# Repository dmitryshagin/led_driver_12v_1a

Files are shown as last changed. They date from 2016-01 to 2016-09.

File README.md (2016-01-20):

***WARNING! IT'S UNTESTED - I'VE NEVER BUILT THIS BOARD. But I will :)***

LED driver for powering Cree XHP35 LED at 1.05A from 3S LiPoly battery to use in underwater flashlight.

It's currently tuned up to work with 9-12.6V input.

Input can be easily changed to 4-25V with slight adjustment of R2 and R3. Increasing voltage over 25V is limited by used capacitors and FETs. You can change it upto ~60V with selecting new Q1-Q5, but PCB rework is also required.

Current is roughly set to 2A with R11, and is fine-tuned to 1.048A with R14&R15. Tuning R14 and R15 values makes it possible to set any current between 0-2A.

This driver is build around [LT3791](http://www.linear.com/product/LT3791)

I've also added Attiny24 to control PWM input and monitor input voltage. It can be ignored and never placed. Firmware will be added later, but the idea is to detect power loss with Q6, go to deep sleep and change working mode on power recovery. C16 gives uC ~4 seconds of life in power down mode, so we can switch power modes with one romote switch. Simulation gave me 10us for uC to go to deep sleep mode and it seems perfect.

You can download [gerbers](binaries/led_driver_12v_1a.zip?raw=true) to order this PCB from [SeedStudio](http://www.seeedstudio.com/service/index.php?r=pcb) - it's very cheap and has nice quality.

[BOM](https://www.digikey.com/classic/RegisteredUser/BOMBillOfMaterials.aspx?path=1&exist=1&id=3307608) - only for registered DigiKey users. Total cost is nearly $27 now.

Yo'll get something like this:

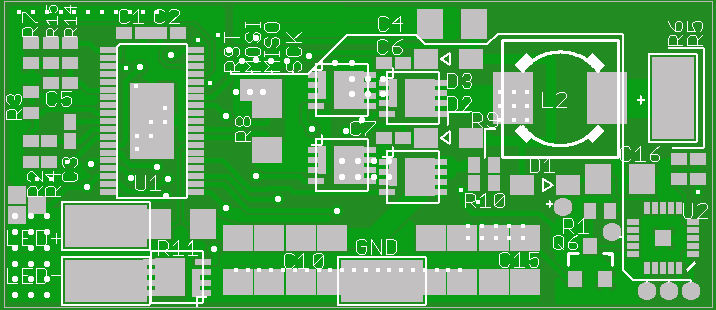
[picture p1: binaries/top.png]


Board is 19.5x35mm and it should generate almost no heat - calculated efficiency is >96.5% and power loss is around 0.4W at 13W output.

It's also round version (32mm):

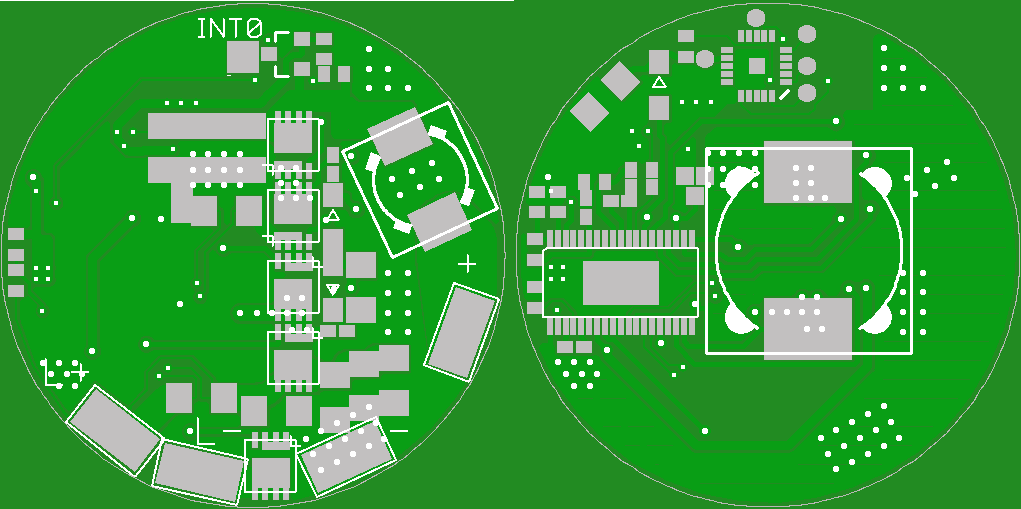
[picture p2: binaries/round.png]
round


[Part List](part_list.txt?raw=true) is also included.

You can also take a look at LTSpice IV simulation and efficiency report. Schematic and PCB created with [Eagle 7.5](http://www.cadsoftusa.com/). It's not as nice and clean as I wanted it to be, but it should do the job.

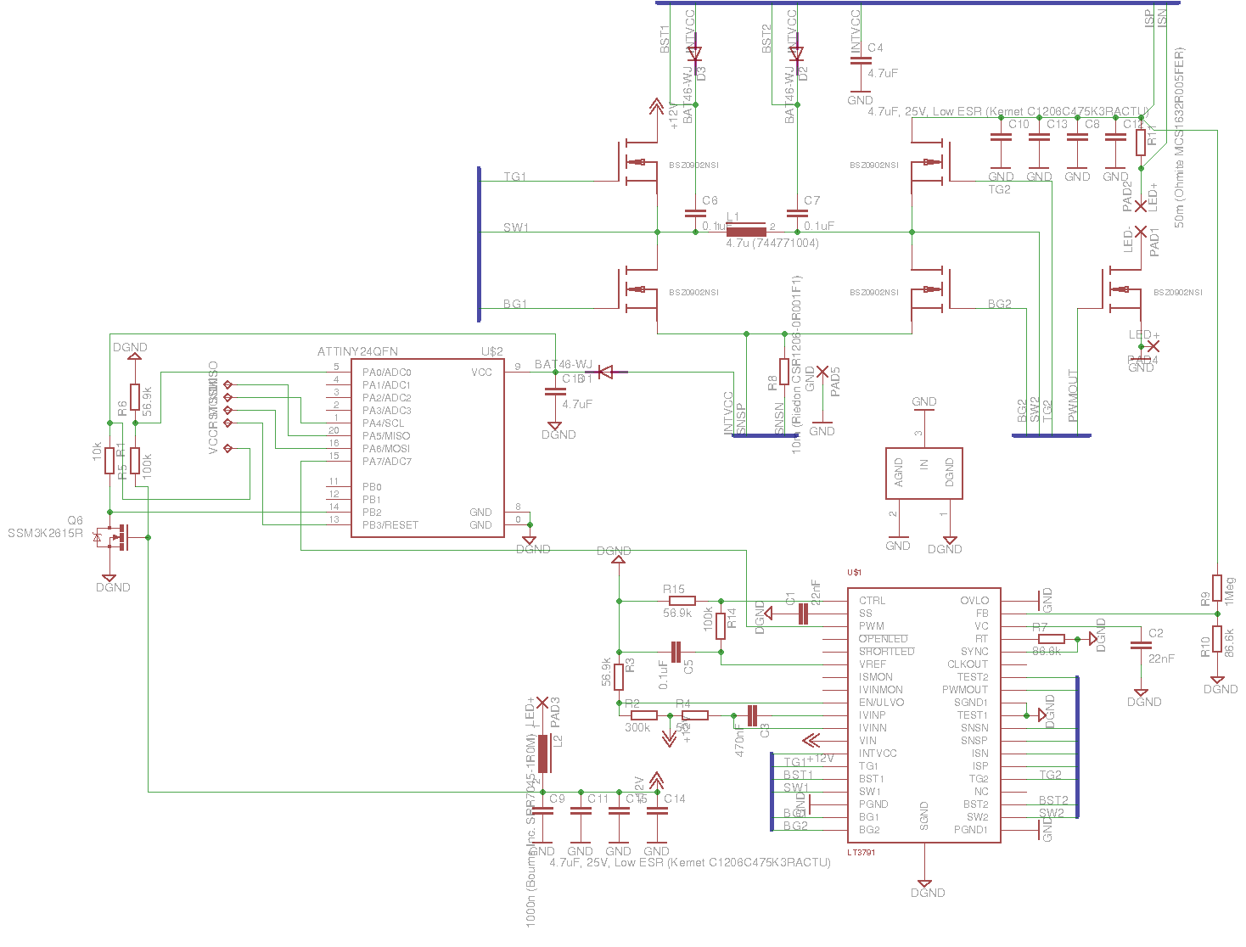
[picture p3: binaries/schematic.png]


**Changes required to use XHP70:**

It is very easy to modify this driver for XHP70 LED (12V version, at 2.4A). Modifications are simple:

* change R11 to 0.033 Ohm (sized 1206, power rating - 0.5 to 1W). Something like Panasonic ERJ-8BWFR033V. It will limit driver output current to 3A
* change R15 to 100k (0402 size) to fine-tune output current at 2.4A.
* change L1 to 10uH with sauration current at least 4A. Wurth Electronics 7447709100 will fit perfectly
* you can also remove L2 to boost efficiency to >98%, but it requires good wireing and low battery impedance (input current will pulse between 2.7 and 3.5Amps (with spikes to 10-15Amps) for 0.01 Ohm battery impedance). Instead we loose ~0.2W at L2, but have no power pulsation on input (<0.04A & stable input current 3.2A).

LTSpice simulation results:

* input power: 36.3W @ 11.7V
* output power: 35.5W @ 2.42A
* calculated efficiency: 97.8%
* LED current pulses: <1.7%

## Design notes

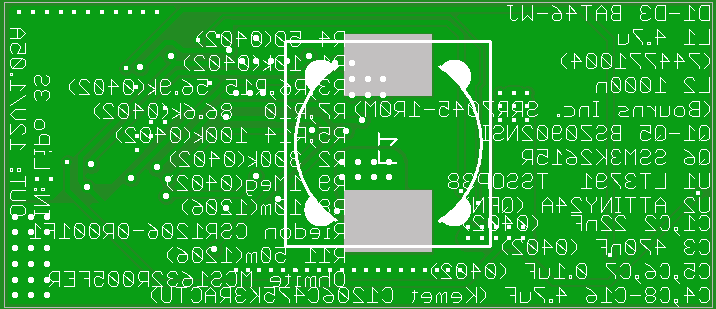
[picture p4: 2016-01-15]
binaries/bottom.png

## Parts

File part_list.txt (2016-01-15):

C1,C2   22nF  (0402)
C3      470nF (0402)
C4,C8-C16 4.7uF (Kemet C1206C475K3RACTU)
C5,C6,C7 0.1uF (0402)
D1-D3    BAT46-WJ
L1       4.7u (744771004)
L2       1000n (Bourns Inc. SRR7045-1R0M)
Q1-Q5    BSZ0902NSI
Q6       SSM3K2615R
R4       50
R1       10k
R3,R6,R15    56.9k
R7,R10       86.6k
R5,R14       100k
R2       300k
R9       1Meg
R8       10m (Riedon CSR1206-0R001F1) (1206)
R11      50m (Ohmite MCS1632R005FER) (1206)
U1      LT3791  TSSOP38
U2      ATTINY24A (QFN)

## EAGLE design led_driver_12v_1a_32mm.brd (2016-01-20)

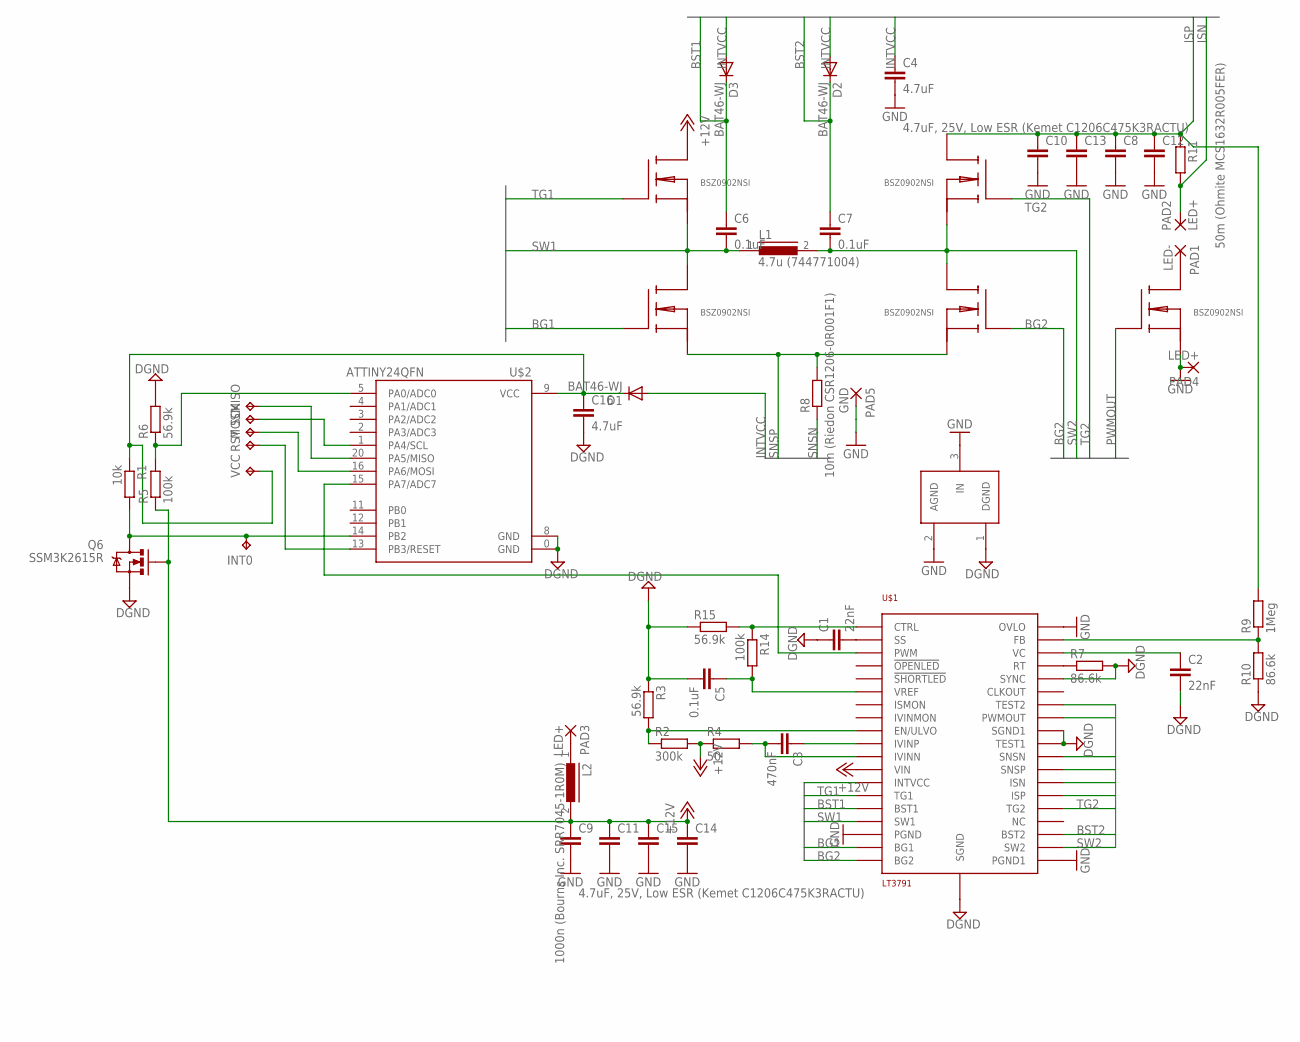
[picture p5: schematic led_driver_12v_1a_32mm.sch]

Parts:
C1: 22nF; C0402
C2: 22nF; C0402K
C3: 470nF; C0402K
C4, C16: 4.7uF; C1206
C5, C6, C7: 0.1uF; C0402K
C8, C9, C10, C11, C12, C13, C14, C15: 4.7uF, 25V, Low ESR (Kemet C1206C475K3RACTU); C1206
D1, D2, D3: BAT46-WJ; SOD323-W
INT0: TPTP20SQ; TP20SQ
L1: 4.7u (744771004); DR127
L2: 1000n (Bourns Inc. SRR7045-1R0M); DR74
MISO: TPTP11R; TP11R
MOSI: TPTP11R; TP11R
PAD1: LED-; 5-2,5
PAD2, PAD3, PAD4: LED+; 5-2,5
PAD5: GND; SMD1,27-2,54
Q1, Q2, Q3, Q4, Q5: BSZ0902NSI; BSZ090X
Q6: SSM3K2615R; SOT23-3
R1: 10k; R0402
R2: 300k; R0402
R3, R6, R15: 56.9k; R0402
R4: 50; R0402
R5, R14: 100k; R0402
R7, R10: 86.6k; R0402
R8: 10m (Riedon CSR1206-0R001F1); R1206
R9: 1Meg; R0402
R11: 50m (Ohmite MCS1632R005FER); R1206
RST: TPTP11R; TP11R
SCK: TPTP11R; TP11R
U$1: LT3791; TSSOP38
U$2: ATTINY24QFN; QFN20
U$4: GND_CONNECT
VCC: TPTP11R; TP11R

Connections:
+12V: C9.1, C11.1, C14.1, C15.1, L2.2, Q1.D, Q1.D@1 (D), Q1.D@2 (D), Q1.D@3 (D), Q1.D@4 (D), Q6.1 (G), R2.2, R4.1, R5.1, U$1.P$12 (VIN)
BG1: Q2.G, U$1.P$18 (BG1)
BG2: Q3.G, U$1.P$19 (BG2)
BST1: C6.1, D3.C, U$1.P$15 (BST1)
BST2: C7.1, D2.C, U$1.P$22 (BST2)
DGND: C1.1, C2.2, C5.2, C16.2, Q6.2 (S), R3.1, R6.2, R7.2, R10.1, R15.1, U$1.P$29 (TEST1), U$1.P$30 (SGND), U$1.P$34 (SYNC), U$1.P$39 (SGND1), U$2.0 (GND), U$2.8 (GND), U$4.1 (DGND)
GND: C4.2, C8.2, C9.2, C10.2, C11.2, C12.2, C13.2, C14.2, C15.2, PAD4.1, PAD5.1, Q5.S@1 (S), Q5.S@2 (S), Q5.S@3 (S), Q5.S@4 (S), U$1.P$17 (PGND), U$1.P$20 (PGND1), U$1.P$38 (OVLO), U$4.2 (AGND), U$4.3 (IN)
INTVCC: C4.1, D1.A, D2.A, D3.A, U$1.P$13 (INTVCC), U$1.P$32 (TEST2)
ISN: PAD2.1, R11.2, U$1.P$26 (ISN)
ISP: C8.1, C10.1, C12.1, C13.1, Q4.D, Q4.D@1 (D), Q4.D@2 (D), Q4.D@3 (D), Q4.D@4 (D), R9.2, R11.1, U$1.P$25 (ISP)
unnamed: C5.1, R14.2, U$1.P$6 (VREF)
unnamed: R14.1, R15.2, U$1.P$1 (CTRL)
unnamed: R7.1, U$1.P$35 (RT)
unnamed: C1.2, U$1.P$2 (SS)
unnamed: C2.1, U$1.P$36 (VC)
unnamed: R9.1, R10.2, U$1.P$37 (FB)
unnamed: C3.1, U$1.P$10 (IVINP)
unnamed: C3.2, R4.2, U$1.P$11 (IVINN)
unnamed: R2.1, R3.2, U$1.P$9 (EN/ULVO)
unnamed: C16.1, D1.C, R1.1, U$2.9 (VCC), VCC.TP
unnamed: INT0.TP, Q6.3 (D), R1.2, U$2.14 (PB2)
unnamed: U$1.P$3 (PWM), U$2.15 (PA7/ADC7)
unnamed: R5.2, R6.1, U$2.5 (PA0/ADC0)
unnamed: MISO.TP, U$2.20 (PA5/MISO)
unnamed: MOSI.TP, U$2.16 (PA6/MOSI)
unnamed: RST.TP, U$2.13 (PB3/RESET)
unnamed: PAD1.1, Q5.D, Q5.D@1 (D), Q5.D@2 (D), Q5.D@3 (D), Q5.D@4 (D)
unnamed: SCK.TP, U$2.1 (PA4/SCL)
unnamed: L2.1, PAD3.1
PWMOUT: Q5.G, U$1.P$31 (PWMOUT)
SNSN: R8.1, U$1.P$28 (SNSN)
SNSP: Q2.S@1 (S), Q2.S@2 (S), Q2.S@3 (S), Q2.S@4 (S), Q3.S@1 (S), Q3.S@2 (S), Q3.S@3 (S), Q3.S@4 (S), R8.2, U$1.P$27 (SNSP)
SW1: C6.2, L1.1, Q1.S@1 (S), Q1.S@2 (S), Q1.S@3 (S), Q1.S@4 (S), Q2.D, Q2.D@1 (D), Q2.D@2 (D), Q2.D@3 (D), Q2.D@4 (D), U$1.P$16 (SW1)
SW2: C7.2, L1.2, Q3.D, Q3.D@1 (D), Q3.D@2 (D), Q3.D@3 (D), Q3.D@4 (D), Q4.S@1 (S), Q4.S@2 (S), Q4.S@3 (S), Q4.S@4 (S), U$1.P$21 (SW2)
TG1: Q1.G, U$1.P$14 (TG1)
TG2: Q4.G, U$1.P$24 (TG2)

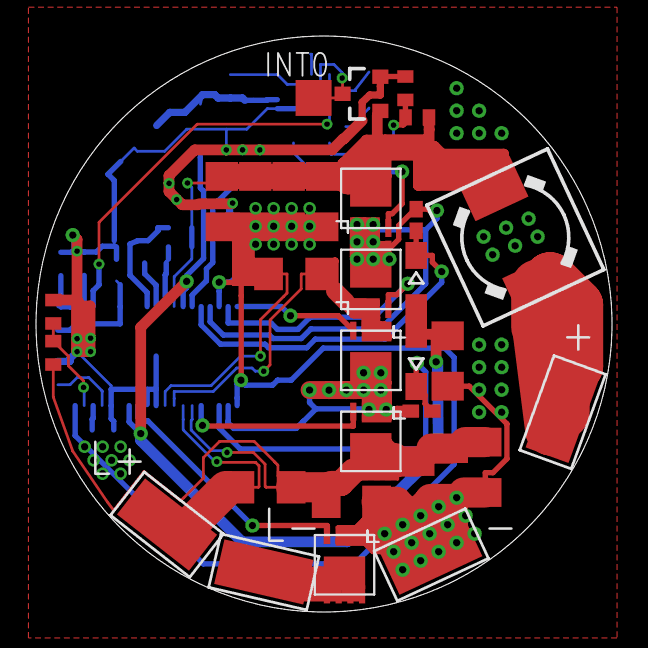
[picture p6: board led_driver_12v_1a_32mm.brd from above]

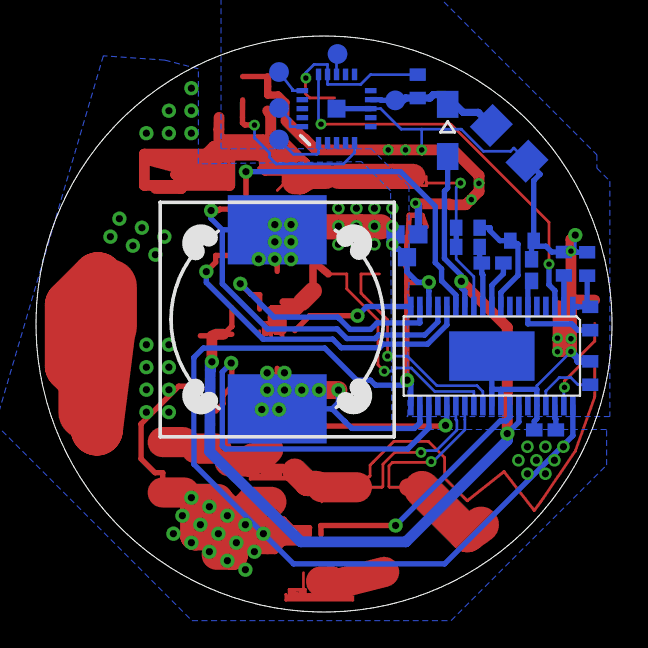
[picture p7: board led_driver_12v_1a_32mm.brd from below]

Board: 2 copper layers, 32.0 x 32.0 mm, 54 parts (22 on the bottom side), 36 nets.

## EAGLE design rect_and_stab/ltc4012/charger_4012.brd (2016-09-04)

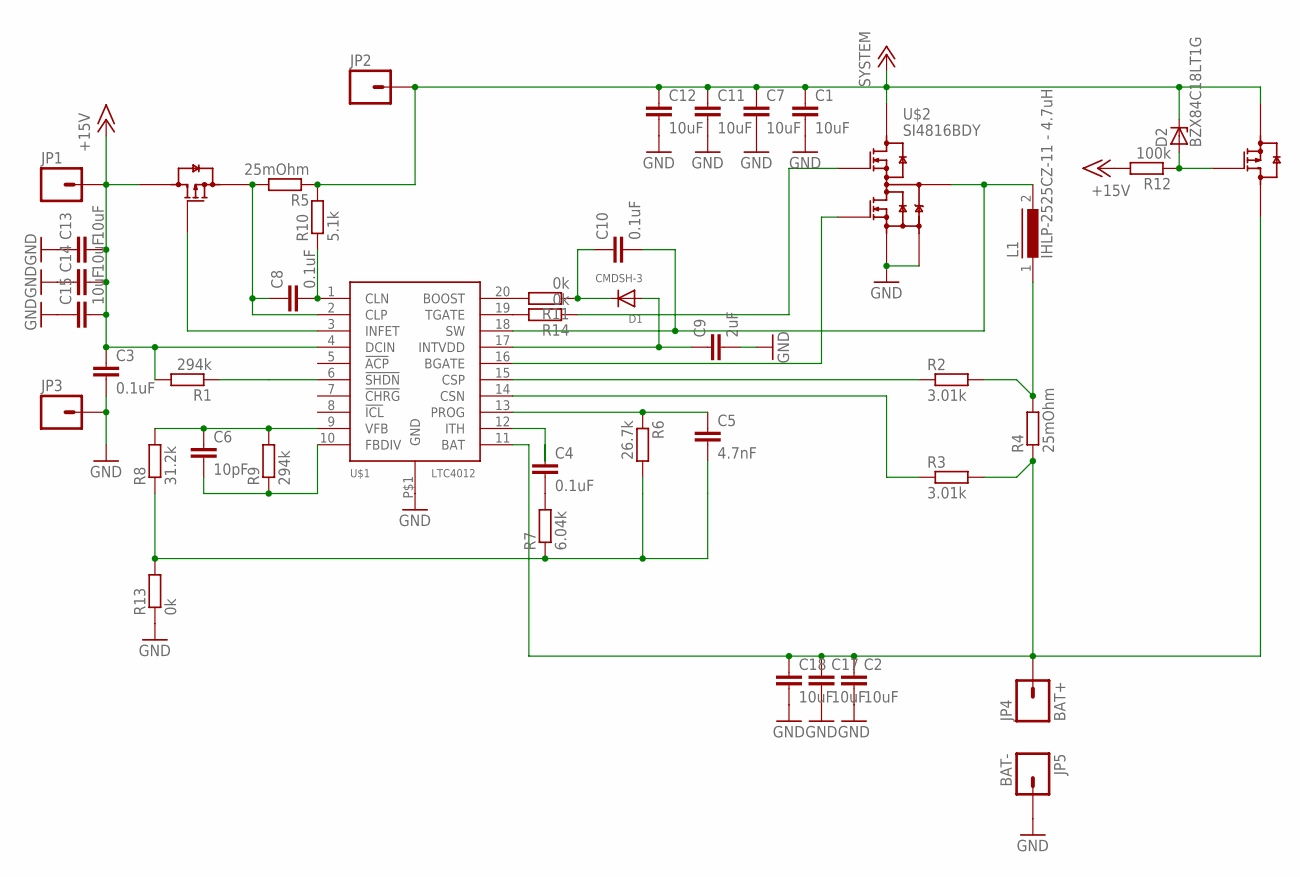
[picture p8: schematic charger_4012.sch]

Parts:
C1, C2, C7, C11, C12, C13, C14, C15, C17, C18: 10uF; C1206
C3, C4, C8, C10: 0.1uF; C0402
C5: 4.7nF; C0402
C6: 10pF; C0402
C9: 2uF; C0805
D1: CMDSH-3; SOD-323F
D2: BZX84C18LT1G; TO236
JP1, JP2, JP3: M01PTH_2MM; 1X01_2MM
JP4: BAT+; 1X01_2MM
JP5: BAT-; 1X01_2MM
L1: IHLP-2525CZ-11 - 4.7uH; DR73
R1, R9: 294k; R0402
R2, R3: 3.01k; R0402
R4, R5: 25mOhm; R2512
R6: 26.7k; R0402
R7: 6.04k; R0402
R8: 31.2k; R0402
R10: 5.1k; R0402
R11, R13, R14: 0k; R0402
R12: 100k; R0402
U$1: LTC4012; QFN20
U$2: SI4816BDY; SO-8
U$3, U$4: SI7423DN; POWERPACK1212

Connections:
+12V: C1.1, C7.1, C11.1, C12.1, D2.C, JP2.1, R5.1, R10.2, U$2.8 (D1), U$4.1 (S), U$4.2 (S), U$4.3 (S)
+15V: C3.1, C13.2, C14.2, C15.2, JP1.1, R1.2, R12.2, U$1.4 (DCIN), U$3.5 (D), U$3.6 (D), U$3.7 (D), U$3.8 (D), U$3.9 (D)
BAT: C2.1, C17.1, C18.1, JP4.1, R3.2, R4.1, U$1.11 (BAT), U$4.5 (D), U$4.6 (D), U$4.7 (D), U$4.8 (D), U$4.9 (D)
BGATE: U$1.16 (BGATE), U$2.4 (G2)
BOOST: C10.1, D1.C, R11.1
CLN: C8.2, R10.1, U$1.1 (CLN)
CSN: R3.1, U$1.14 (CSN)
CSP: R2.1, U$1.15 (CSP)
FBDIV: C6.2, R9.1, U$1.10 (FBDIV)
GND: C1.2, C2.2, C3.2, C7.2, C9.2, C11.2, C12.2, C13.1, C14.1, C15.1, C17.2, C18.2, JP3.1, JP5.1, R13.1, U$1.P$1 (GND), U$2.2 (A), U$2.3 (S2)
INFET: U$1.3 (INFET), U$3.4 (G)
INTVDD: C9.1, D1.A, U$1.17 (INTVDD)
ITH: C4.1, U$1.12 (ITH)
unnamed: R14.2, U$1.19 (TGATE)
unnamed: L1.1, R2.2, R4.2
unnamed: C4.2, R7.2
unnamed: R1.1, U$1.6 (!SHDN)
unnamed: C8.1, R5.2, U$1.2 (CLP), U$3.1 (S), U$3.2 (S), U$3.3 (S)
unnamed: R11.2, U$1.20 (BOOST)
unnamed: D2.A, R12.1, U$4.4 (G)
PROG: C5.1, R6.1, U$1.13 (PROG)
SGND: C5.2, R6.2, R7.1, R8.1, R13.2
SW: C10.2, L1.2, U$1.18 (SW), U$2.5 (S1/D2), U$2.6 (S1/D2), U$2.7 (S1/D2)
TGATE: R14.1, U$2.1 (G1)
VFB: C6.1, R8.2, R9.2, U$1.9 (VFB)

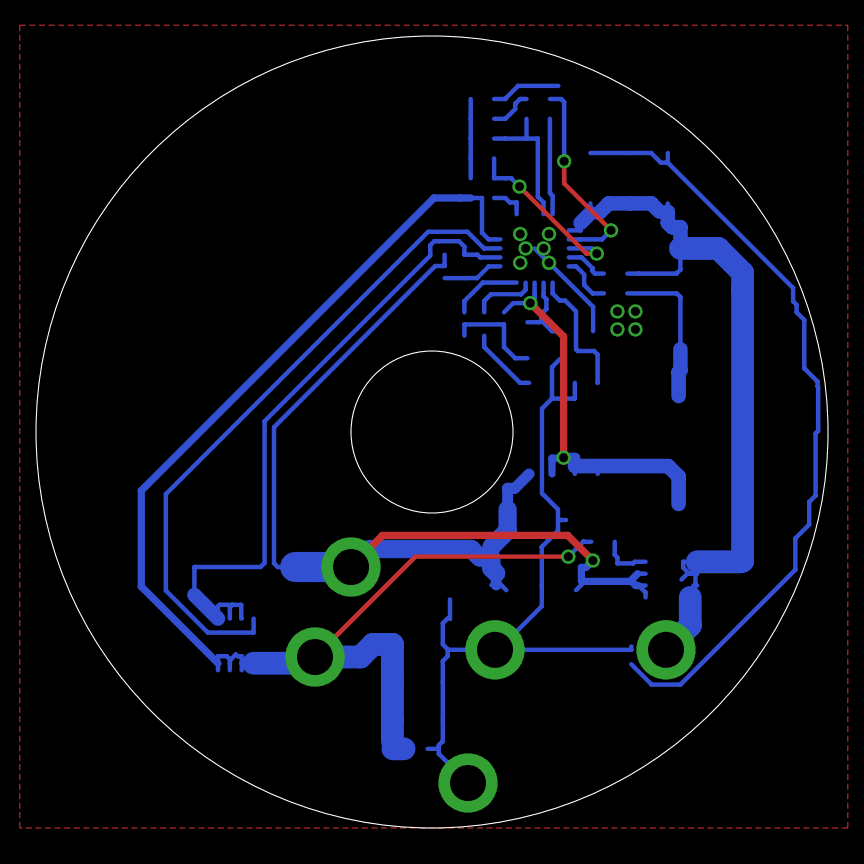
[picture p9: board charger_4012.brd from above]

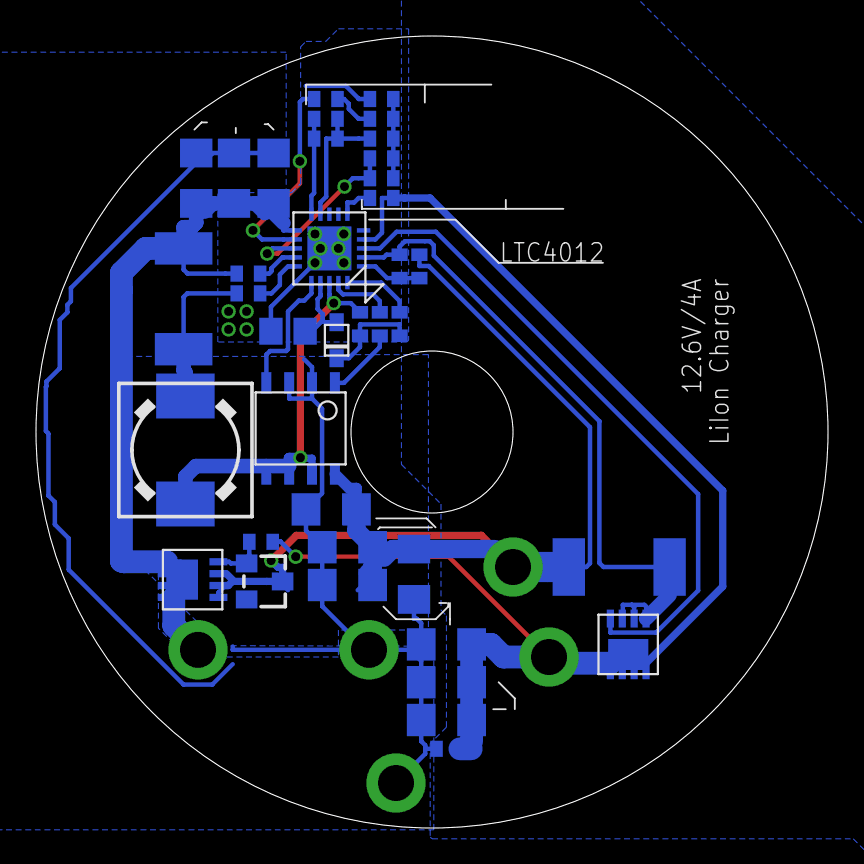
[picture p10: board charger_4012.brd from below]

Board: 2 copper layers, 44.0 x 44.0 mm, 43 parts (38 on the bottom side), 25 nets.

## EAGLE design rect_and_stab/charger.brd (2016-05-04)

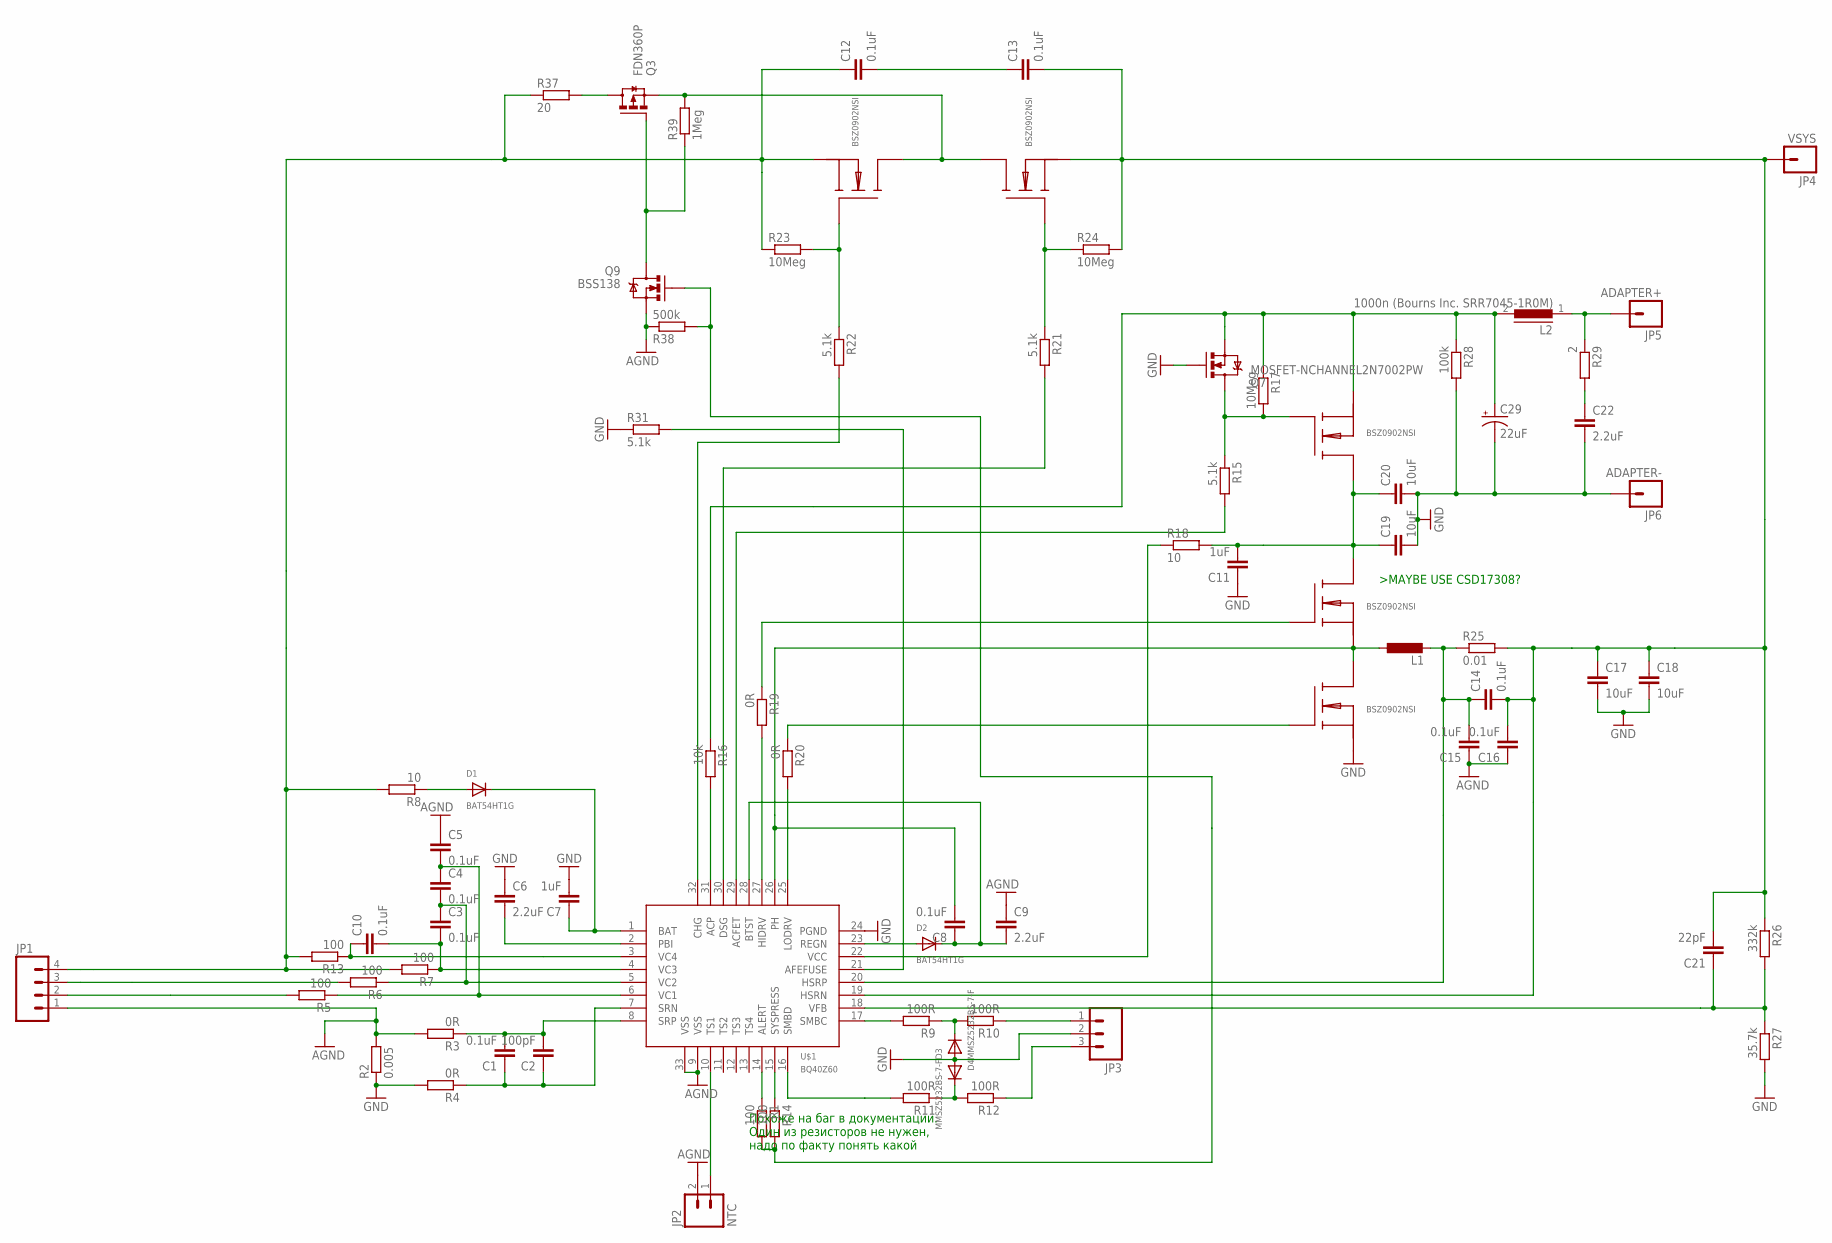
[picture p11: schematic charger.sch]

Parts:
C1, C3, C4, C5, C8, C10, C12, C13, C14, C15, C16: 0.1uF; C0402
C2: 100pF; C0402
C6, C9, C22: 2.2uF; C0805
C7: 1uF; C0603
C11: 1uF; C0805
C17, C18, C19, C20: 10uF; C1206
C21: 22pF; C0402
C29: 22uF; EIA7343
D1, D2: BAT54HT1G; SOD-323F
D3, D4: MMSZ5232BS-7-F; SOD-323F
JP1: M04PTH; 1X04
JP2: NTC; 1X02
JP3: M03PTH; 1X03
JP4: VSYS; 1X01_2MM
JP5: ADAPTER+; 1X01_2MM
JP6: ADAPTER-; 1X01_2MM
L1: L-EUL5650M; L5650M
L2: 1000n (Bourns Inc. SRR7045-1R0M); DR74
Q1, Q2, Q4, Q5, Q8: BSZ0902NSI; BSZ090X
Q3: FDN360P; SUPER-SOT3
Q7: MOSFET-NCHANNEL2N7002PW; SOT323
Q9: BSS138; SOT323
R1, R14: 100; R0402
R2: 0.005; R1210
R3, R4, R19, R20: 0R; R0402
R5, R6, R7, R13: 100; R0603
R8: 10; R0603
R9, R10, R11, R12: 100R; R0402
R15, R21, R22, R31: 5.1k; R0402
R16: 10k; R0402
R17, R23, R24: 10Meg; R0402
R18: 10; R1206
R25: 0.01; R2010
R26: 332k; R0402
R27: 35.7k; R0402
R28: 100k; R0402
R29: 2; R0603
R37: 20; R1210
R38: 500k; R0402
R39: 1Meg; R0402
U$1: BQ40Z60

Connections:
AGND: C5.1, C9.1, C15.1, C16.1, JP1.1, JP2.2, Q9.2 (S), R2.2, R3.2, R38.1, U$1.9 (VSS), U$1.33 (VSS)
GND: C6.1, C7.2, C11.1, C17.2, C18.2, C19.2, C20.2, C22.2, C29.C (-), D3.A, D4.A, JP3.2, JP6.1, Q2.S@1 (S), Q2.S@2 (S), Q2.S@3 (S), Q2.S@4 (S), Q7.1 (G), R2.1, R4.2, R27.2, R28.2, R31.1, U$1.24 (PGND)
unnamed: C1.2, C2.2, R3.1, U$1.8 (SRP)
unnamed: C1.1, C2.1, R4.1, U$1.7 (SRN)
unnamed: JP1.2, R5.2
unnamed: C7.1, D1.C, U$1.1 (BAT)
unnamed: C4.1, C5.2, R5.1, U$1.6 (VC1)
unnamed: C3.2, C10.2, R7.1, U$1.4 (VC3)
unnamed: JP1.4, R7.2, R8.2, R13.2
unnamed: JP1.3, R6.2
unnamed: C3.1, C4.2, R6.1, U$1.5 (VC2)
unnamed: C6.2, U$1.2 (PBI)
unnamed: D1.A, R8.1
unnamed: JP2.1, U$1.10 (TS1)
unnamed: R1.1, U$1.14 (ALERT)
unnamed: R9.2, U$1.17 (SMBC)
unnamed: R11.2, U$1.16 (SMBD)
unnamed: C10.1, R13.1, U$1.3 (VC4)
unnamed: D4.C, R11.1, R12.2
unnamed: D3.C, R9.1, R10.2
unnamed: JP3.1, R10.1
unnamed: C22.1, R29.2
unnamed: Q3.2 (S), Q4.D, Q4.D@1 (D), Q4.D@2 (D), Q4.D@3 (D), Q4.D@4 (D), Q5.D, Q5.D@1 (D), Q5.D@2 (D), Q5.D@3 (D), Q5.D@4 (D), R39.2
unnamed: JP3.3, R12.1
unnamed: D2.A, U$1.23 (REGN)
unnamed: C8.1, C9.2, D2.C, U$1.28 (BTST)
unnamed: R31.2, U$1.21 (AFEFUSE)
unnamed: C12.1, Q4.S@1 (S), Q4.S@2 (S), Q4.S@3 (S), Q4.S@4 (S), R23.1, R37.1
unnamed: C11.2, C19.1, C20.1, Q1.D, Q1.D@1 (D), Q1.D@2 (D), Q1.D@3 (D), Q1.D@4 (D), Q8.D, Q8.D@1 (D), Q8.D@2 (D), Q8.D@3 (D), Q8.D@4 (D), R18.2
unnamed: C8.2, L1.1, Q1.S@1 (S), Q1.S@2 (S), Q1.S@3 (S), Q1.S@4 (S), Q2.D, Q2.D@1 (D), Q2.D@2 (D), Q2.D@3 (D), Q2.D@4 (D), U$1.26 (PH)
unnamed: Q7.3 (D), Q8.G, R15.1, R17.2
unnamed: R15.2, U$1.29 (ACFET)
unnamed: R16.2, U$1.31 (ACP)
unnamed: R18.1, U$1.22 (VCC)
unnamed: C21.1, R26.2, R27.1, U$1.18 (VFB)
unnamed: R19.2, U$1.27 (HIDRV)
unnamed: R20.2, U$1.25 (LODRV)
unnamed: Q1.G, R19.1
unnamed: Q2.G, R20.1
unnamed: R21.2, U$1.30 (DSG)
unnamed: Q5.G, R21.1, R24.1
unnamed: R22.2, U$1.32 (CHG)
unnamed: Q4.G, R22.1, R23.2
unnamed: C12.2, C13.1
unnamed: C14.1, C15.2, L1.2, R25.1, U$1.20 (HSRP)
unnamed: C13.2, C14.2, C16.2, C17.1, C18.1, C21.2, JP4.1, Q5.S@1 (S), Q5.S@2 (S), Q5.S@3 (S), Q5.S@4 (S), R24.2, R25.2, R26.1, U$1.19 (HSRN)
unnamed: Q3.3 (D), R37.2
unnamed: Q9.1 (G), R1.2, R14.2, R38.2
unnamed: Q3.1 (G), Q9.3 (D), R39.1
unnamed: R14.1, U$1.15 (SYSPRESS)
unnamed: C29.A (+), L2.2, Q7.2 (S), Q8.S@1 (S), Q8.S@2 (S), Q8.S@3 (S), Q8.S@4 (S), R16.1, R17.1, R28.1
unnamed: JP5.1, L2.1, R29.1

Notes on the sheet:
Похоже на баг в документации. Один из резисторов не нужен, надо по факту понять какой

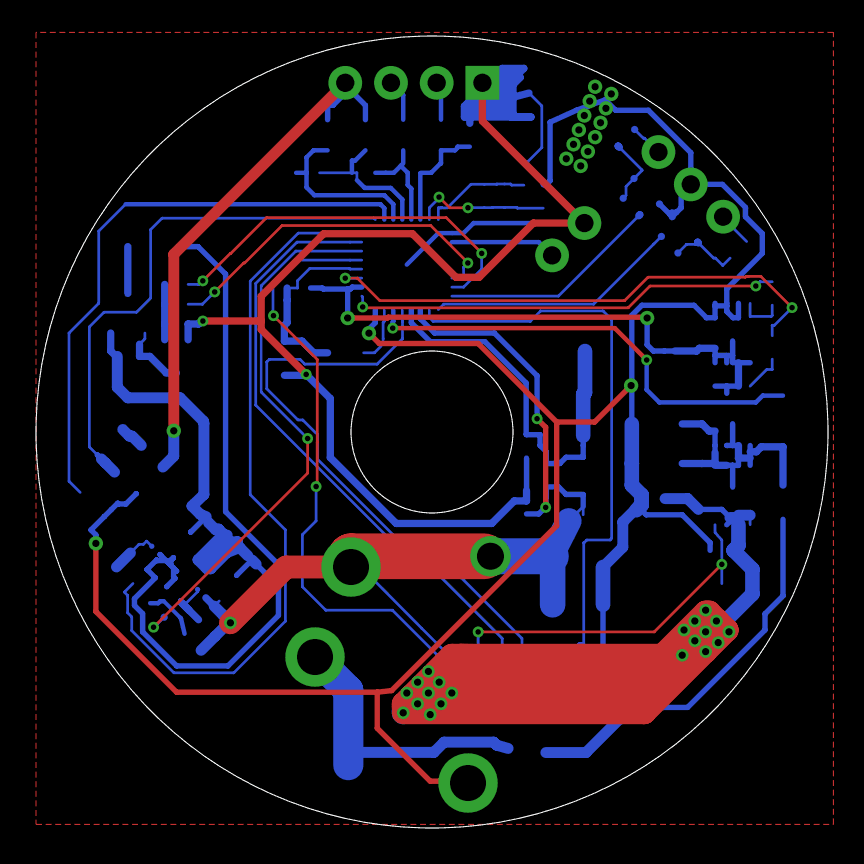
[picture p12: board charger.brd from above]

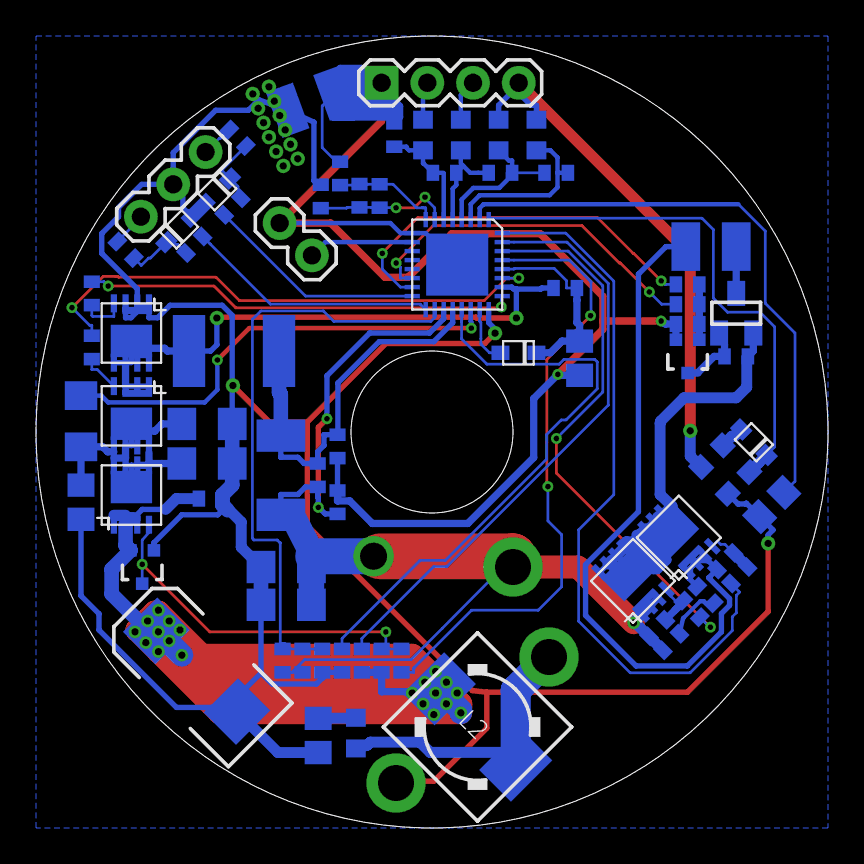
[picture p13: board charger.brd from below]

Board: 2 copper layers, 44.0 x 44.0 mm, 77 parts (74 on the bottom side), 52 nets.

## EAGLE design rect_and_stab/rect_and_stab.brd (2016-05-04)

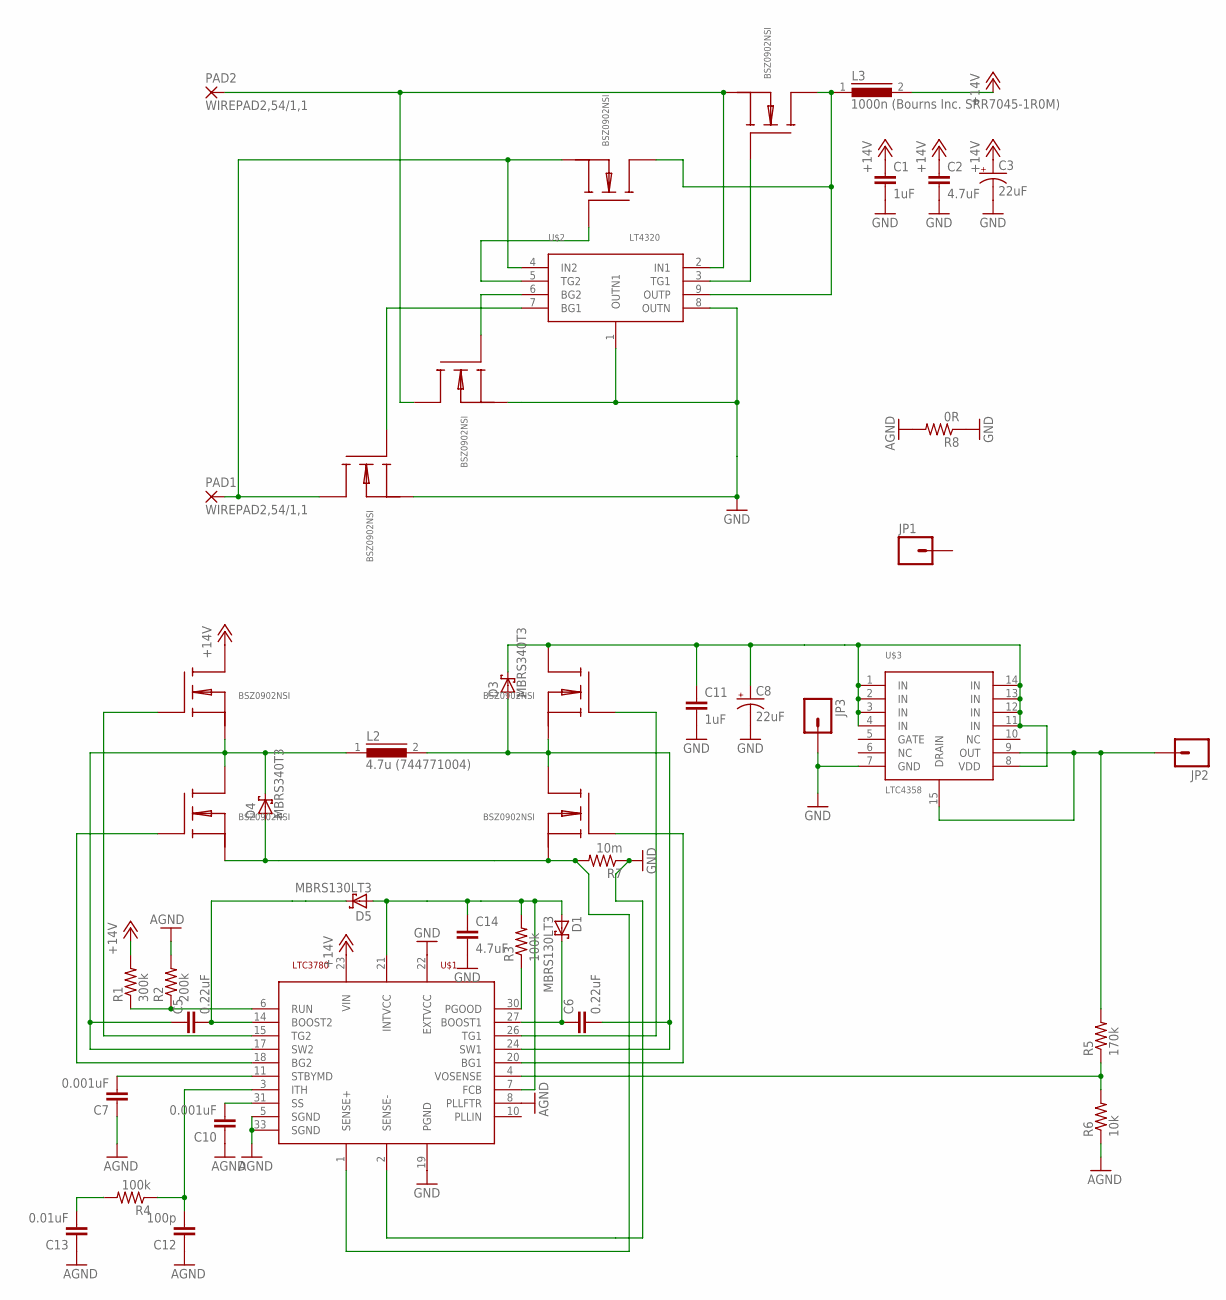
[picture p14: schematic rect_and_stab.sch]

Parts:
C1, C11: 1uF; 0603-CAP
C2, C14: 4.7uF; 1210
C3, C8: 22uF; EIA7343
C5, C6: 0.22uF; 0603-CAP
C7, C10: 0.001uF; 0402-CAP
C12: 100p; 0402-CAP
C13: 0.01uF; 0402-CAP
D1, D5: MBRS130LT3; SMB
D3, D4: MBRS340T3; SMC
JP1, JP2, JP3: M01PTH_2MM; 1X01_2MM
L2: 4.7u (744771004); DR127
L3: 1000n (Bourns Inc. SRR7045-1R0M); DR74
PAD1, PAD2: WIREPAD2,54/1,1; 2,54/1,1
Q1, Q2, Q3, Q4, Q5, Q6, Q7, Q8: BSZ0902NSI; BSZ090X
R1: 300k; 0402-RES
R2: 200k; 0402-RES
R3, R4: 100k; 0402-RES
R5: 170k; 0402-RES
R6: 10k; 0402-RES
R7: 10m; R2010
R8: 0R; 0402-RES
U$1: LTC3780
U$2: LT4320
U$3: LTC4358

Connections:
+12V: C1.1, C2.1, C3.A (+), L3.2, Q6.D, Q6.D@1 (D), Q6.D@2 (D), Q6.D@3 (D), Q6.D@4 (D), R1.2, U$1.23 (VIN)
AGND: C7.1, C10.1, C12.1, C13.1, R2.2, R6.1, R8.2, U$1.5 (SGND), U$1.8 (PLLFTR), U$1.33 (SGND)
GND: C1.2, C2.2, C3.C (-), C8.C (-), C11.2, C14.2, JP3.1, Q1.S@1 (S), Q1.S@2 (S), Q1.S@3 (S), Q1.S@4 (S), Q3.S@1 (S), Q3.S@2 (S), Q3.S@3 (S), Q3.S@4 (S), R7.1, R8.1, U$1.2 (SENSE-), U$1.19 (PGND), U$1.22 (EXTVCC), U$2.1 (OUTN1), U$2.8 (OUTN), U$3.7 (GND)
unnamed: Q2.G, U$2.5 (TG2)
unnamed: PAD1.1, Q2.S@1 (S), Q2.S@2 (S), Q2.S@3 (S), Q2.S@4 (S), Q3.D, Q3.D@1 (D), Q3.D@2 (D), Q3.D@3 (D), Q3.D@4 (D), U$2.4 (IN2)
unnamed: Q3.G, U$2.7 (BG1)
unnamed: C7.2, U$1.11 (STBYMD)
unnamed: C6.1, D1.C, U$1.27 (BOOST1)
unnamed: Q1.G, U$2.6 (BG2)
unnamed: PAD2.1, Q1.D, Q1.D@1 (D), Q1.D@2 (D), Q1.D@3 (D), Q1.D@4 (D), Q4.S@1 (S), Q4.S@2 (S), Q4.S@3 (S), Q4.S@4 (S), U$2.2 (IN1)
unnamed: Q4.G, U$2.3 (TG1)
unnamed: L3.1, Q2.D, Q2.D@1 (D), Q2.D@2 (D), Q2.D@3 (D), Q2.D@4 (D), Q4.D, Q4.D@1 (D), Q4.D@2 (D), Q4.D@3 (D), Q4.D@4 (D), U$2.9 (OUTP)
unnamed: Q7.G, U$1.20 (BG1)
unnamed: C6.2, D3.A, L2.2, Q7.D, Q7.D@1 (D), Q7.D@2 (D), Q7.D@3 (D), Q7.D@4 (D), Q8.S@1 (S), Q8.S@2 (S), Q8.S@3 (S), Q8.S@4 (S), U$1.24 (SW1)
unnamed: C10.2, U$1.31 (SS)
unnamed: JP2.1, R5.2, U$3.9 (OUT), U$3.15 (DRAIN)
unnamed: Q8.G, U$1.26 (TG1)
unnamed: Q5.G, U$1.18 (BG2)
unnamed: C5.1, D4.C, L2.1, Q5.D, Q5.D@1 (D), Q5.D@2 (D), Q5.D@3 (D), Q5.D@4 (D), Q6.S@1 (S), Q6.S@2 (S), Q6.S@3 (S), Q6.S@4 (S), U$1.17 (SW2)
unnamed: Q6.G, U$1.15 (TG2)
unnamed: C5.2, D5.C, U$1.14 (BOOST2)
unnamed: R5.1, R6.2, U$1.4 (VOSENSE)
unnamed: R1.1, R2.1, U$1.6 (RUN)
unnamed: R3.1, U$1.30 (PGOOD)
unnamed: C8.A (+), C11.1, D3.C, Q8.D, Q8.D@1 (D), Q8.D@2 (D), Q8.D@3 (D), Q8.D@4 (D), U$3.1 (IN), U$3.2 (IN), U$3.3 (IN), U$3.4 (IN), U$3.8 (VDD), U$3.11 (IN), U$3.12 (IN), U$3.13 (IN), U$3.14 (IN)
unnamed: D4.A, Q5.S@1 (S), Q5.S@2 (S), Q5.S@3 (S), Q5.S@4 (S), Q7.S@1 (S), Q7.S@2 (S), Q7.S@3 (S), Q7.S@4 (S), R7.2, U$1.1 (SENSE+)
unnamed: C13.2, R4.2
unnamed: C12.2, R4.1, U$1.3 (ITH)
unnamed: C14.1, D1.A, D5.A, R3.2, U$1.7 (FCB), U$1.21 (INTVCC)

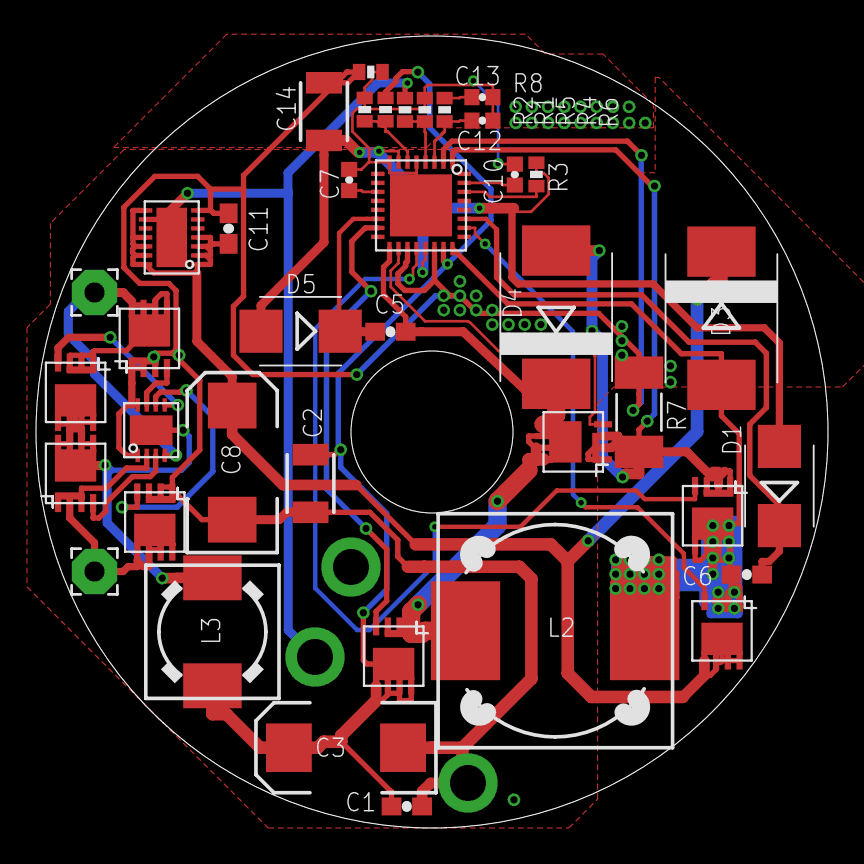
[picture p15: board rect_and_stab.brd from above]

Board: 2 copper layers, 44.0 x 44.0 mm, 42 parts (0 on the bottom side), 29 nets.

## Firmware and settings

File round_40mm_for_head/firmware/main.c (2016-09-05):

#include <avr/io.h>
#include <avr/delay.h>
#include <avr/interrupt.h>
#include <avr/sleep.h>
#include <avr/eeprom.h>
#include <string.h>

#define MODE_OFF			0
#define MODE_IDLE			1
#define MODE_OVERTEMP		2
#define MODE_LOW_VOLTAGE	3
#define MODE_LOW			4
#define MODE_HALF			5
#define MODE_FULL			6


#define LIMIT_9V  714
#define LIMIT_10V 793
#define LIMIT_11V 872
#define LIMIT_12V 951

#define BLUE_OFF 			(PORTA |=  (1<<PA4))
#define BLUE_ON 			(PORTA &= ~(1<<PA4))
#define GREEN_OFF 			(PORTA |=  (1<<PA3))
#define GREEN_ON 			(PORTA &= ~(1<<PA3))
#define RED_OFF  			(PORTA |=  (1<<PA2))
#define RED_ON  			(PORTA &= ~(1<<PA2))

#define LEFT_PRESSED 		(!(PINB & (1 << PB1)))
#define RIGHT_PRESSED 		(!(PINB & (1 << PB2)))

#define DRIVER_ON  			(PORTB |=  (1<<PB0))
#define DRIVER_OFF 			(PORTB &= ~(1<<PB0))


volatile uint8_t power_mode, prev_power_mode, unlock_stage, d_seconds, adc_channel, vals_pos=0;
volatile uint16_t vals[4];
volatile uint32_t val;
volatile uint32_t seconds;

uint32_t nv_seconds_on[] EEMEM = {0,0,0,0,0,0,0};
uint16_t nv_times_on[]   EEMEM = {0,0,0,0,0,0,0};
uint16_t nv_max_on[]     EEMEM = {0,0,0,0,0,0,0};

uint8_t times_occured[6];
const uint8_t zero_vals[6] = {0,0,0,0,0,0};

uint8_t led_selected, old_led_selected = 0;

uint32_t seconds_on[7];
uint16_t times_on[7];
uint16_t max_on[7];

ISR(ADC_vect){
	uint8_t theLowADC = ADCL;
	val = ADCH<<8 | theLowADC;
	ADCSRA |= 1<<ADSC;	//start conversion
}

ISR(PCINT1_vect){
	read_button();
}

ISR(TIM1_OVF_vect){
	d_seconds+=1;
	if(d_seconds==10){
		seconds+=1;
		d_seconds=0;
	}
	TCNT1 = 53035; //~=10Hz
}


void all_off(){
	stop_timer();
	unlock_stage = 0;
	seconds = 0;
	d_seconds = 0;
	apply_led(0);
	power_mode = MODE_OFF;
	apply_power();
	DRIVER_OFF;
	OCR0B=0;
	led_selected = 0;
	old_led_selected = 0;
	disable_adc();
	clean_times_occured();
}

void start_timer(){
	TCCR1A = 0;
	TCNT1 = 53035; 		 //~=10Hz
	TCCR1B = (1<<CS11);
	TIMSK1 = (1<<TOIE1); //timer1 interrupt enabled
	enable_adc();
	ADCSRA |= (1<<ADSC); //start ADC conversion
}

void stop_timer(){
	TIMSK1 = 0;
	TCCR1B = 0;
}

int apply_power(void){
	if(unlock_stage>0){
		RED_ON;
	}
	if(unlock_stage==3){ //unlock finished
		power_mode = MODE_IDLE;
		unlock_stage = 0;
	}
	if(power_mode==255){power_mode=MODE_IDLE;}
	if(power_mode>MODE_FULL){power_mode=MODE_FULL;}

	if(power_mode==MODE_OFF){
		DRIVER_OFF;
		OCR0B=0;
	}else{
		DRIVER_ON;
		set_sleep_mode(SLEEP_MODE_IDLE);
		sleep_disable();
		// stop_timer();
		start_timer();
	}
	// if(power_mode==MODE_IDLE)		{OCR0B=0;  }
	// if(power_mode==MODE_LOW_VOLTAGE){OCR0B=0; }
	// if(power_mode==MODE_OVERTEMP)	{OCR0B=0;  }
	// if(power_mode==MODE_LOW)		{OCR0B=16; }
	// if(power_mode==MODE_HALF)		{OCR0B=0;}
	// if(power_mode==MODE_FULL)		{OCR0B=0;}
	if(power_mode==MODE_IDLE)		{OCR0B=0;  }
	if(power_mode==MODE_LOW_VOLTAGE){OCR0B=16; }
	if(power_mode==MODE_OVERTEMP)	{OCR0B=8;  }
	if(power_mode==MODE_LOW)		{OCR0B=64; }
	if(power_mode==MODE_HALF)		{OCR0B=127;}
	if(power_mode==MODE_FULL)		{OCR0B=255;}

	if(prev_power_mode!=power_mode){
		seconds_on[prev_power_mode] += seconds;
		times_on[prev_power_mode] += 1;
		if(max_on[prev_power_mode] < seconds){
			max_on[prev_power_mode] = seconds;
		}
		if(power_mode==MODE_LOW_VOLTAGE||power_mode==MODE_OFF){
			//will store data only on power off or low batt to save eeprom
			eeprom_write_block(&seconds_on, &nv_seconds_on, sizeof(seconds_on));
			eeprom_write_block(&times_on,   &nv_times_on,   sizeof(times_on) );
			eeprom_write_block(&max_on,     &nv_max_on,     sizeof(max_on)   );
		}
		prev_power_mode=power_mode;
		seconds=0;
	}

	return 0;
}

void read_button(void){
	_delay_ms(200);
	uint32_t lock_timer=0;
	start_timer();
	if(LEFT_PRESSED){
		old_led_selected = led_selected;
		led_selected = 0;
		RED_OFF;GREEN_OFF;BLUE_ON;
		if(power_mode==MODE_OFF){
			if(unlock_stage==0 || unlock_stage==2){
				unlock_stage+=1;
				old_led_selected = 1;
			}
		}else{
			if(power_mode>MODE_LOW){
				power_mode-=1;
			}else{
				power_mode=1;
			}
		}
		apply_power();
		while(LEFT_PRESSED){lock_timer+=1;if(lock_timer==100000){all_off();}};
		apply_led(old_led_selected);
		_delay_ms(200);
		return;
	}
	if(RIGHT_PRESSED){
		old_led_selected = led_selected;
		led_selected = 0;
		RED_OFF;GREEN_OFF;BLUE_ON;
		if(power_mode==MODE_OFF){
			if(unlock_stage==1){
				unlock_stage+=1;
				old_led_selected = 1;
			}
		}else{
			if(power_mode>=MODE_LOW){ // проскакиваем аварийные режимы
				power_mode+=1;
			}else{
				power_mode=MODE_LOW;
			}
		}
		apply_power();
		while(RIGHT_PRESSED){};
		apply_led(old_led_selected);
		_delay_ms(200);
	}

}

void enable_adc(){
	ADCSRA = (1<<ADEN) | (1<<ADPS2) | (1<<ADPS1) | (1<<ADPS0) | (1<<ADIE);	// enable ADC on 1mhz/16 with interrupt
}

void disable_adc(){
	ADCSRA = 0;
}

void clean_times_occured(){
	memcpy(times_occured, zero_vals, sizeof(zero_vals));
}

int check_and_set_times(uint8_t idx){
	uint8_t prev = 0;
	prev = times_occured[idx];
	clean_times_occured();
	times_occured[idx]=prev+1;
	if(prev>4){
		clean_times_occured();
		return 1;
	}else{
		return 0;
	}
}

void apply_led(uint8_t led){
	if(led==0){
		RED_OFF;GREEN_OFF;BLUE_OFF;
	}
	if(led==1){
		RED_ON;GREEN_OFF;BLUE_OFF;
	}
	if(led==2){
		RED_OFF;GREEN_OFF;BLUE_ON;
	}
	if(led==3){
		RED_OFF;GREEN_ON;BLUE_OFF;
	}
}

int main(void){
	// PA0 - ADC IN
	// PA2 - RED
	// PA3 - GREEN
	// PA4 - BLUE
	// PA7(OC0B) - PWM output.
	// PB0 - out (EN)
	// PB1 - hall1, PB2 - hall2

	DDRA   = 0b11111110;
	PORTA  = 0b00000000;

	DDRB   = 0b0001;
	PORTB  = 0b0110;

	TCCR0A = (1 << COM0B1) | (1 << WGM00);// | (1 << WGM01);  		// PWM mode
	TCCR0B = (1 << CS01);							// clock source = CLK/8, start PWM

	PCMSK1 = (1<<PCINT9) | (1<<PCINT10);
	GIMSK = (1<<PCIE1);//interrupt on pin change0

	ADMUX = 0b10000000; // ADC0 - int

	apply_led(1);
	DRIVER_ON;
	OCR0B = 8;
	_delay_ms(500);
	all_off();

	eeprom_read_block(&seconds_on, &nv_seconds_on, sizeof(seconds_on));
	eeprom_read_block(&times_on,   &nv_times_on,   sizeof(times_on)  );
	eeprom_read_block(&max_on,     &nv_max_on,     sizeof(max_on)    );
	prev_power_mode = MODE_OFF;
	sei();

	while(1){
		// ADC8 = 330 - ~70 degrees Celcium
		// 9V =  714
		// 10V = 793
		// 11V = 872
		// 12V = 951
		// 12.6V = 999
		if(power_mode==MODE_OFF && unlock_stage==0){
			seconds = 0;
			d_seconds = 0;
			stop_timer();
			disable_adc();
			set_sleep_mode(SLEEP_MODE_PWR_DOWN);
			sleep_enable();
			sleep_bod_disable();
			sleep_cpu();
			sleep_disable();
		}
		if(seconds>1 && power_mode==MODE_OFF){
			all_off();
		}
		if(unlock_stage==0 && power_mode!=MODE_OFF){
			if(d_seconds==0){
				adc_channel = 0;
				ADMUX = 0b10000000; // ADC0 - int
			}
			if(d_seconds==5){
				adc_channel = 1;
				ADMUX = 0b10100010; // int reference and temp sensor
			}

			if(seconds%2==0){
				if(power_mode==MODE_LOW_VOLTAGE){
					RED_ON;GREEN_OFF;BLUE_OFF;
				}
				if(power_mode==MODE_OVERTEMP){
					RED_ON;GREEN_ON;BLUE_OFF;
				}
			}else{
				if(power_mode==MODE_OVERTEMP||power_mode==MODE_LOW_VOLTAGE){
					apply_led(0);
				}
			}

			// if((seconds%5==0) && ADMUX == 0b10000000){ //measure voltage in active mode
			if(adc_channel ==0 && d_seconds == 4){ //measure voltage in active mode
				if(val<LIMIT_9V){
					if(check_and_set_times(0)){
					  all_off();//completely discharged. turning off
					}
				}
				else if(power_mode!=MODE_OVERTEMP && power_mode!=MODE_LOW_VOLTAGE && power_mode>=MODE_IDLE){ //show voltage always, except overtemp
					if(val<((LIMIT_9V+LIMIT_10V)/2)){
						if(power_mode>=MODE_LOW && check_and_set_times(1)){ // усвловие нужно, чтобы не задалбывать функцию - в ней будут логи
							apply_led(0);
							power_mode = MODE_LOW_VOLTAGE;//low voltage
							apply_power();
						}
					}else if(val<LIMIT_10V){
						if(led_selected==0 || check_and_set_times(2) ){
							apply_led(1);
						}
						led_selected = 1;
					}else if(val<LIMIT_11V){
						if(led_selected==0 || check_and_set_times(3)){
							apply_led(2);
						}
						led_selected = 2;
					}else{
						if(led_selected==0 || check_and_set_times(4)){
							apply_led(3);
						}
						led_selected = 3;
					}
				}
			}
			while(d_seconds==4){}

			if(adc_channel ==1 && d_seconds == 8){ //measure temp in active mode
				if(val>330 && power_mode>=MODE_LOW && check_and_set_times(5)){// усвловие нужно, чтобы не задалбывать функцию - в ней будут логи
					power_mode = MODE_OVERTEMP;
					apply_power(); //overtemp. reduce current cunsumption
				}
			}
			while(d_seconds==8){}

			if(power_mode==MODE_IDLE && seconds>=7200){ //выключение через два часа из режима простоя
				all_off();
			}


			// if(seconds==0 && d_seconds<5 && power_mode>=MODE_LOW){
			// 	GIMSK = 0;//вырубим прерывания на первые 500мс, чтобы не кнопать кнопкой сильно часто
			// }else{
			// 	GIMSK = (1<<PCIE1);//interrupt on pin change0
			// }
		}
	}
}

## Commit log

2016-01-13 schematics roughly finished, components are roughly in place. Need accurate routing and fine component adjustments
    [led_driver_12v_1a.brd, led_driver_12v_1a.sch]
2016-01-13 second iteration of component placement. already have routing improvements, but still plenty of work to do
    [led_driver_12v_1a.brd, led_driver_12v_1a.sch]
2016-01-14 routing complete. main tasks to do: add polys, optimize routes width, add some extra vias, make gerbers
    [led_driver_12v_1a.brd, led_driver_12v_1a.sch]
2016-01-14 added poly's & some traces optimization. Need to pretify silkscreen, check everything and make gerbers
    [led_driver_12v_1a.brd]
2016-01-15 Added Gerbers and PartList
    [led_driver_12v_1a.GBL, led_driver_12v_1a.GBO, led_driver_12v_1a.GBP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]
2016-01-15 Added BOM to readme
2016-01-20 added round version
    [led_driver_12v_1a_round.GBL, led_driver_12v_1a_round.GBO, led_driver_12v_1a_round.GBP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]
2016-01-21 added vias for led in roud version, added second button pad in round version
    [led_driver_12v_1a_round.brd, led_driver_12v_1a_round.sch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]
2016-02-05 added 40mm version
    [led_driver_12v_1a_round.GBL, led_driver_12v_1a_round.GBO, led_driver_12v_1a_round.GBP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]
2016-02-05 kevlin connection changed
    [led_driver_12v_1a_round.brd, led_driver_12v_1a_round.sch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]
2016-03-12 added rectifier and stab
    [charger.brd, charger.sch, rect_and_stab.brd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]
2016-04-29 board routed and secondary protection removed
    [charger.brd, charger.sch, rect_and_stab.brd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]
2016-05-04 mirrored charger board. this version has been ordered (charger&rect_and_stab)
    [charger.brd, rect_and_stab.brd]
2016-06-13 added adc resistors shutdown
    [led_driver_12v_1a_round.brd, led_driver_12v_1a_round.sch]
2016-06-22 added resistor to adc
    [led_driver_12v_1a_round.brd, led_driver_12v_1a_round.sch]
2016-07-18 firmware - added sleep mode and timer
2016-07-25 moved components inside
    [led_driver_12v_1a_round.brd]
2016-08-12 added ltc4012 version of charger
    [charger_4012.brd, charger_4012.sch]
2016-09-05 added 5 times check before switch
2017-08-07 Restores 32mm version
    [led_driver_12v_1a_32mm.brd, led_driver_12v_1a_32mm.sch]

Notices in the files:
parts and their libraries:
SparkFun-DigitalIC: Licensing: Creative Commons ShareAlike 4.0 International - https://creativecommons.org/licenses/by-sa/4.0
